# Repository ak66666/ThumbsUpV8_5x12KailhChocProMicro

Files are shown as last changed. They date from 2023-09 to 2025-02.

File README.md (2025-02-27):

# ThumbsUp! v8 5x12 Keyboard for Kailh Choc and Gateron Low Profile switches dirven by ProMicro and pin-compatibles

Multilevel 58 Key Ergonomic Contoured Mechanical Keyboard.

The board uses Kailh Choc and Gateron Low Profile Switches with hot-swap sockets.

ProMicro or pin-compatible MCUs are supported, including Raspberry RP2040 with [QMK, see this fork.](https://github.com/ak66666/qmk_firmware/tree/thumbsup_20240523/keyboards/thumbsup)

Supports Proglide Cirque touchpad (up to 40mm diameter).

Can be made wireless with nice!nano v2 and a battery, [ZMK firmware.](https://github.com/ak66666/zmk-config/tree/master)

# Photos

Black PCBs - v8 with Kailh Choc switches, PCBs are 1.6mm thick
Red PCBs - v8b with Gateron Low Profile switches, PCB thickness is 1.2mm, GLP switch pins are too short (or rather are tapered at the ends too much), what creates poor/unstable contact with the sockets in 1.6mm PCBs.

v8 with Kailh Choc Blue switches
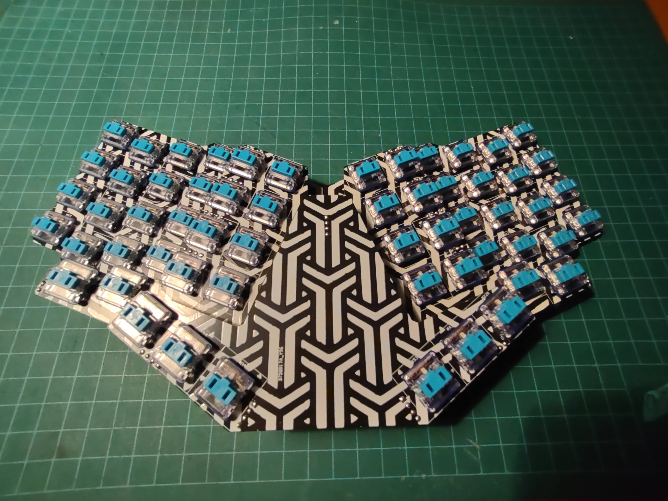
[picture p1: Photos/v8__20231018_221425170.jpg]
v8 with Kailh Choc Blue switches

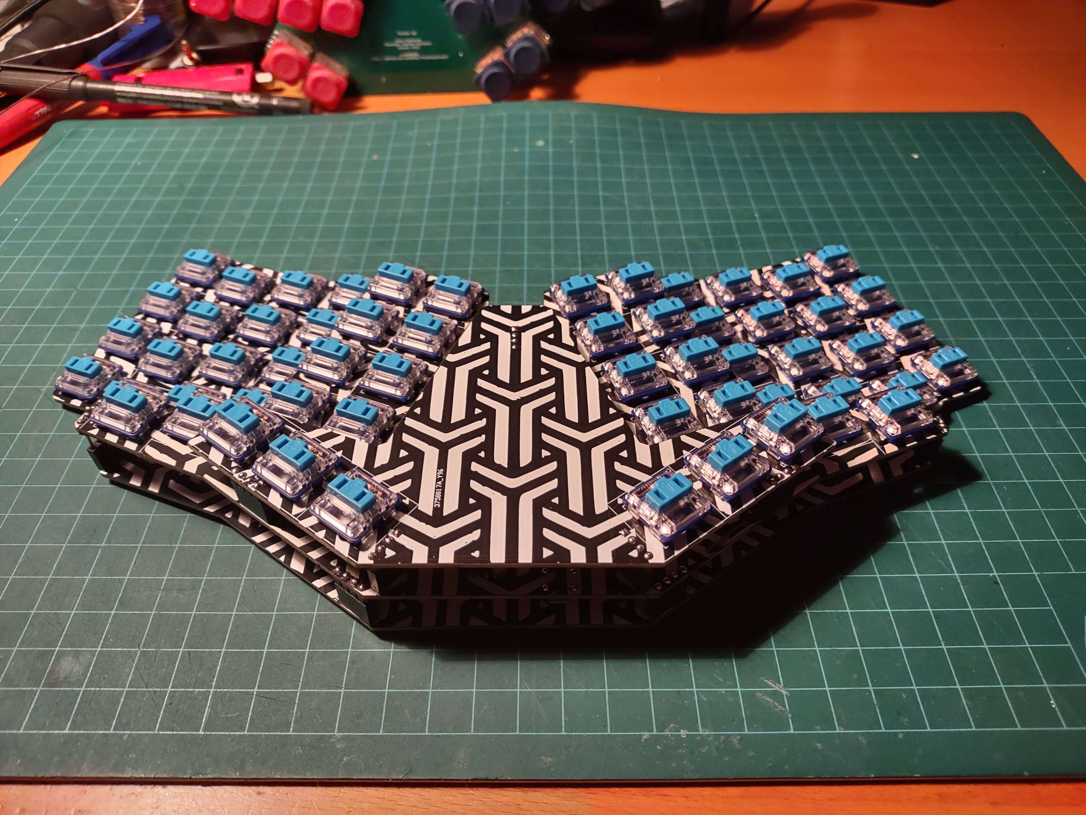
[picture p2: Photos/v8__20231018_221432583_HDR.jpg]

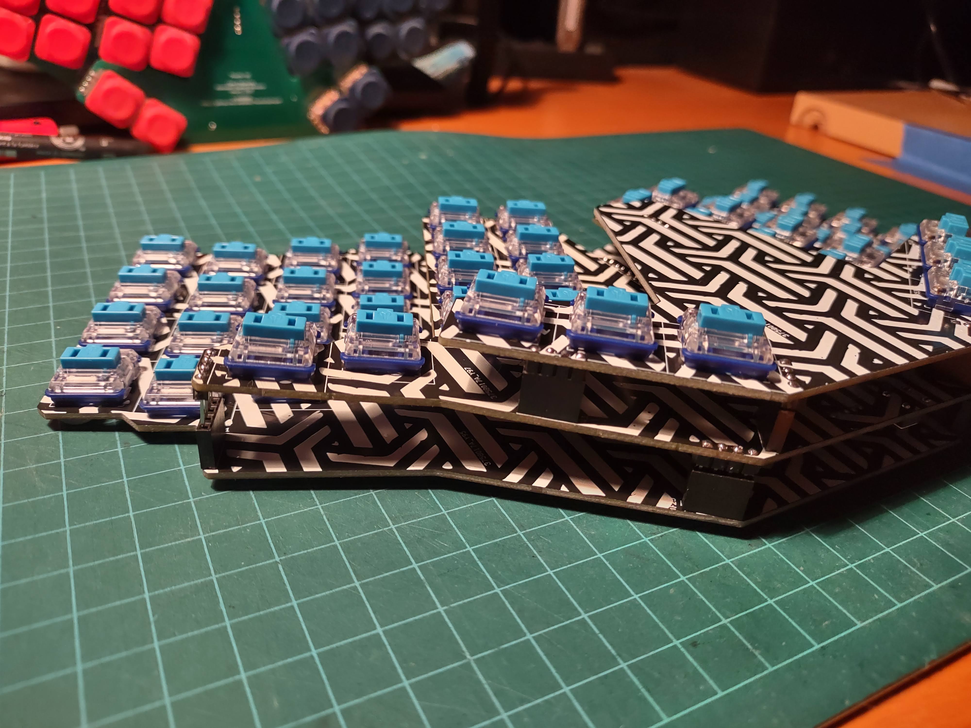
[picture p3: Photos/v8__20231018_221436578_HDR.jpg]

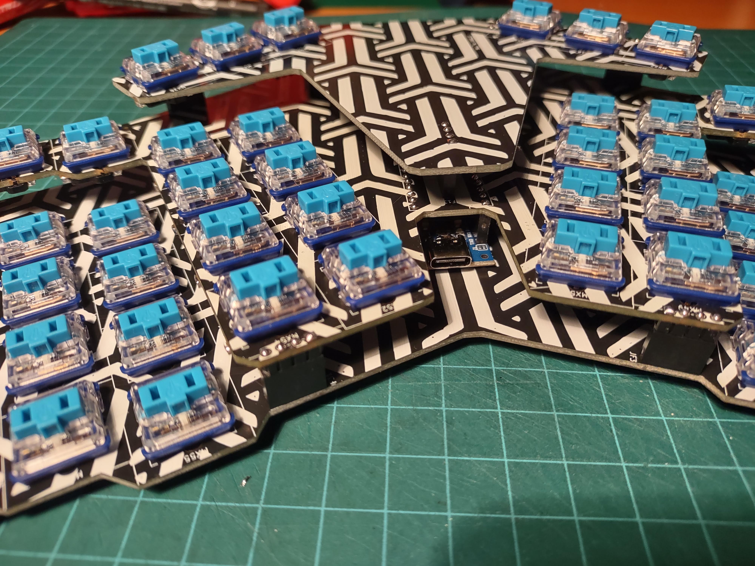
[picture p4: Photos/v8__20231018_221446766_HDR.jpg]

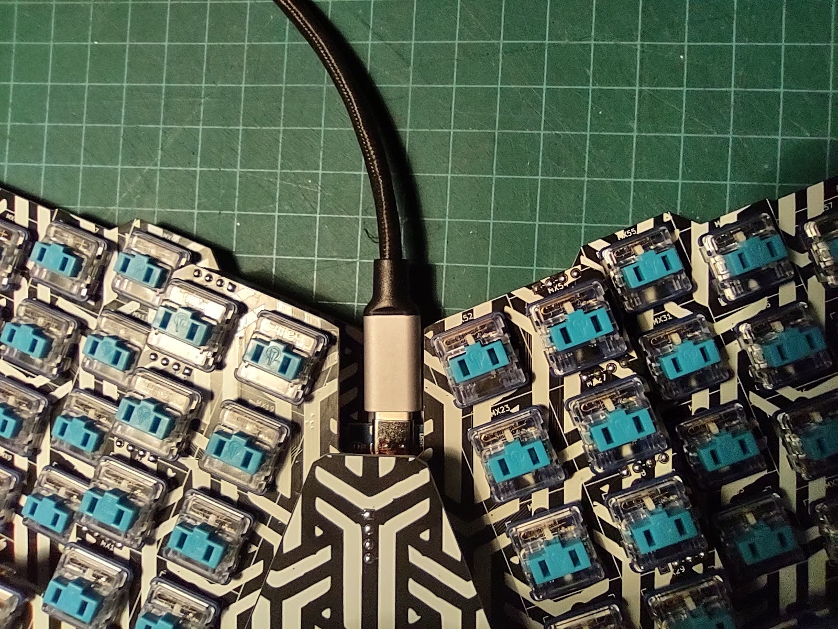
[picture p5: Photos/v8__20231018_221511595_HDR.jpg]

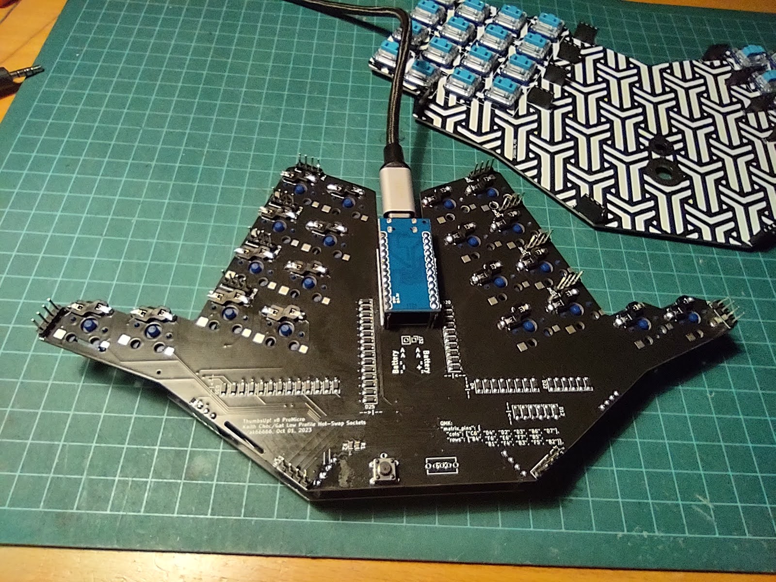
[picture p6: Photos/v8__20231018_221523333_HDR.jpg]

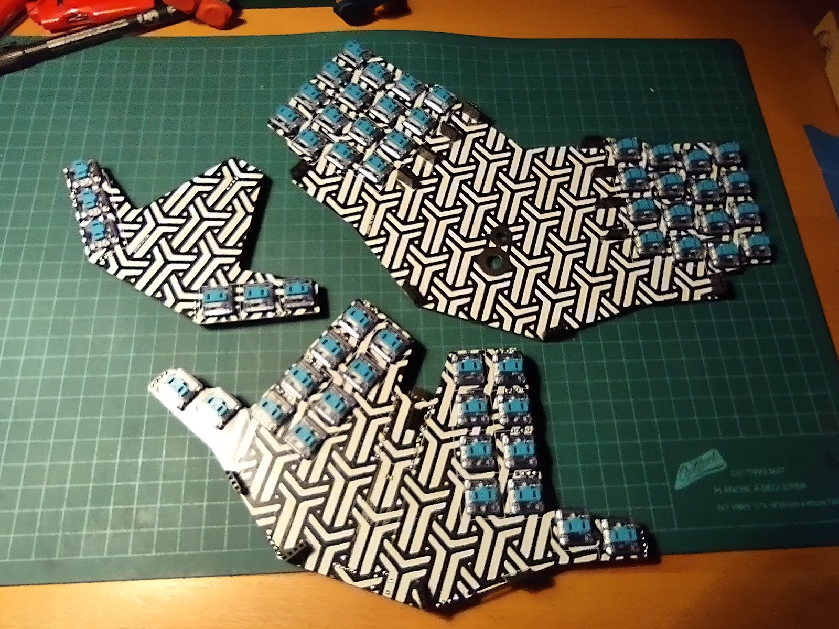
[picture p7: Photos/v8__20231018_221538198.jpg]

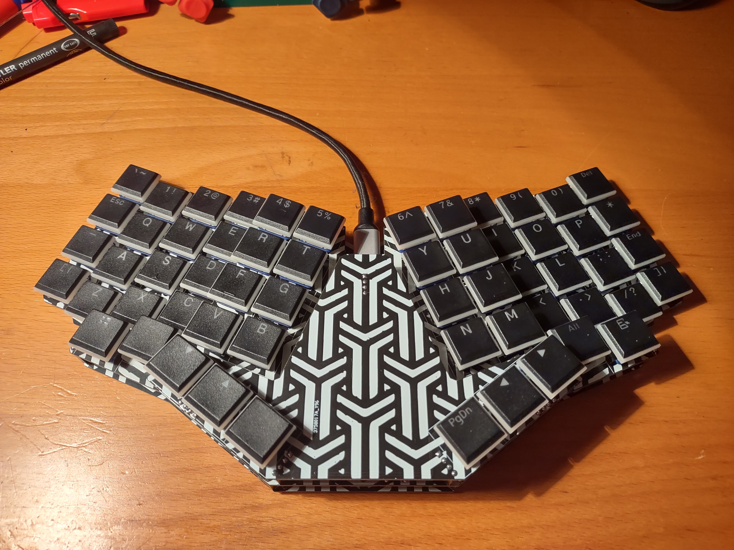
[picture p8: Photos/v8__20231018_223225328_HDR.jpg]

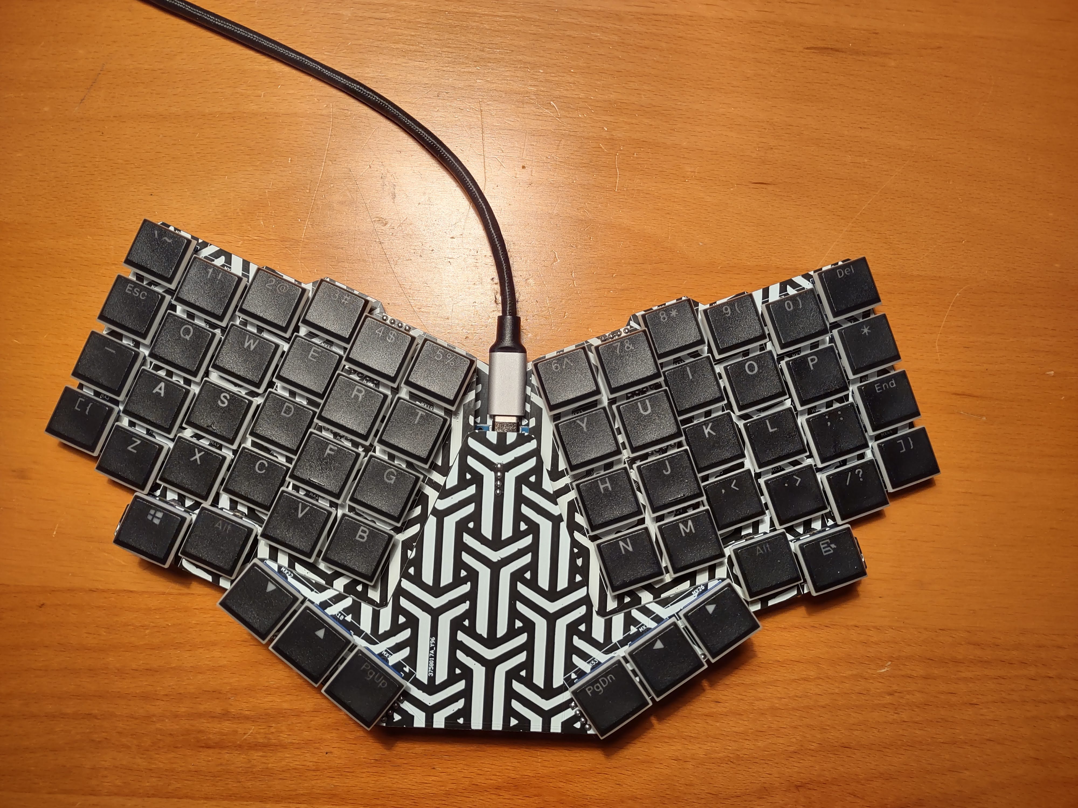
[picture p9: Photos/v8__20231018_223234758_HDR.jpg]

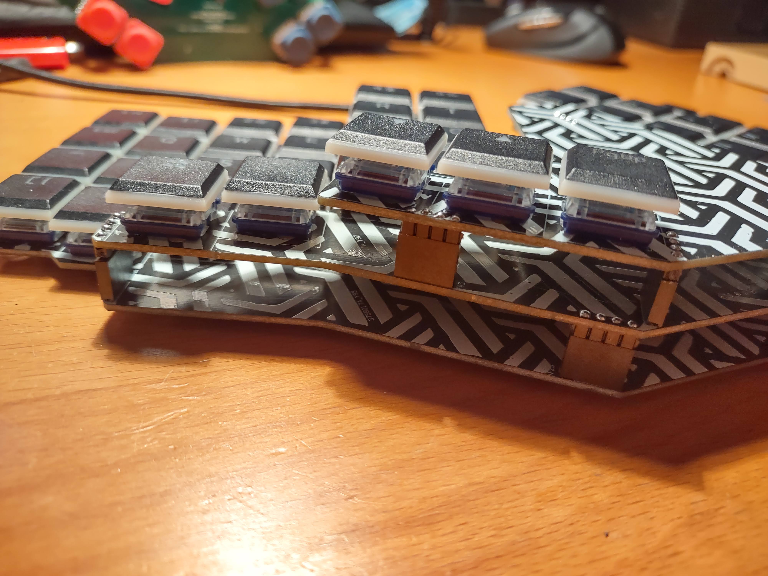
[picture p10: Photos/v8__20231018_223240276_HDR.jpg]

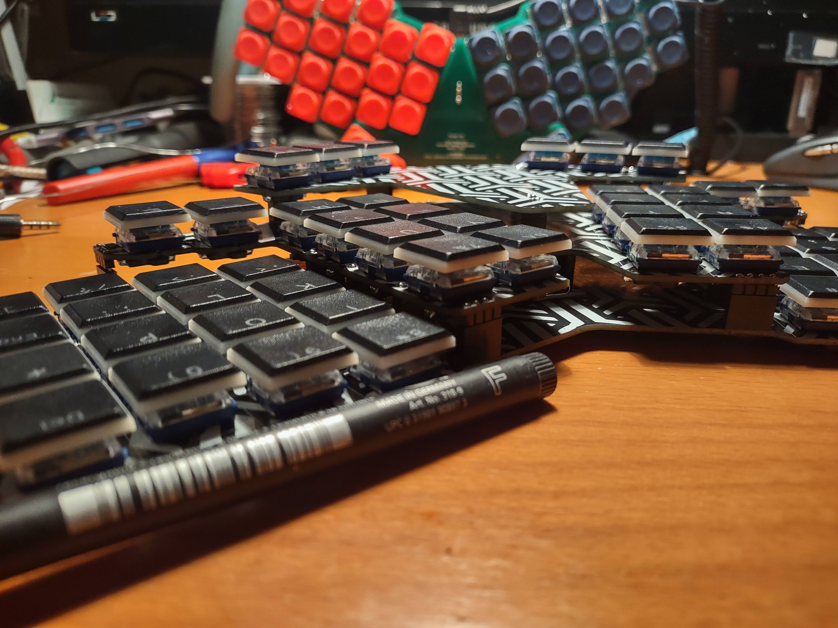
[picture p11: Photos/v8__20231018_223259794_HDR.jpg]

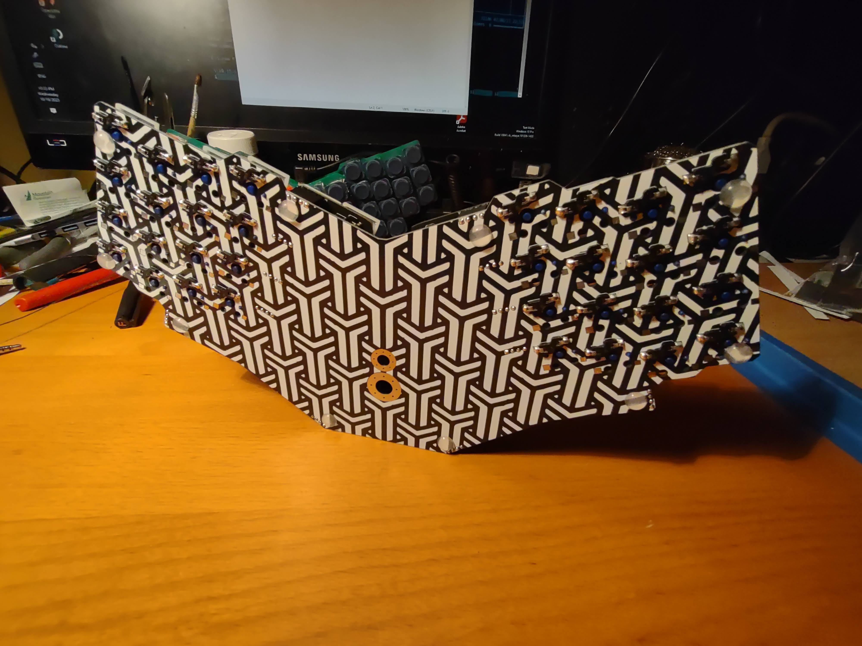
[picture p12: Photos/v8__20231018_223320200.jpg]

ThumbsUp! v2 and v8
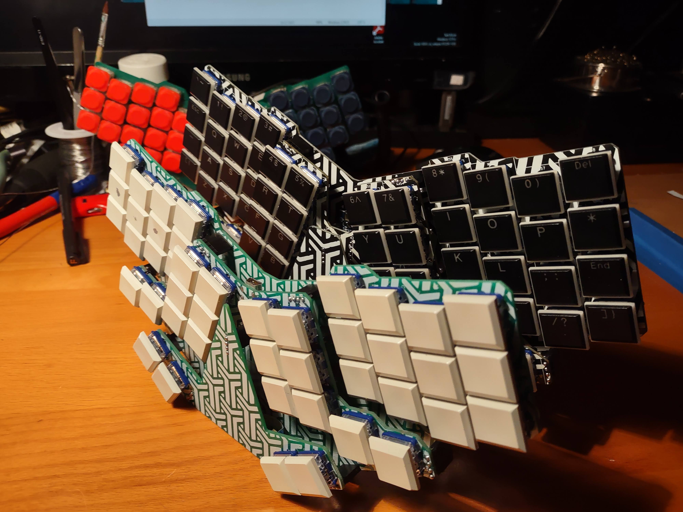
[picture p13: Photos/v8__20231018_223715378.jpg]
ThumbsUp! v2 and v8

ThumbsUp! v8 and v5
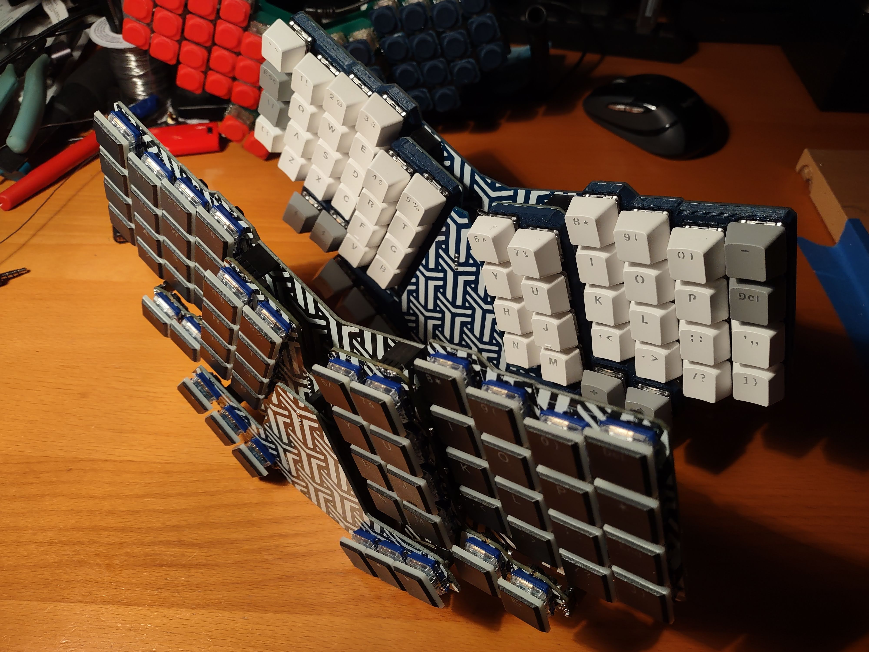
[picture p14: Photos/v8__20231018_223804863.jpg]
ThumbsUp! v8 and v5

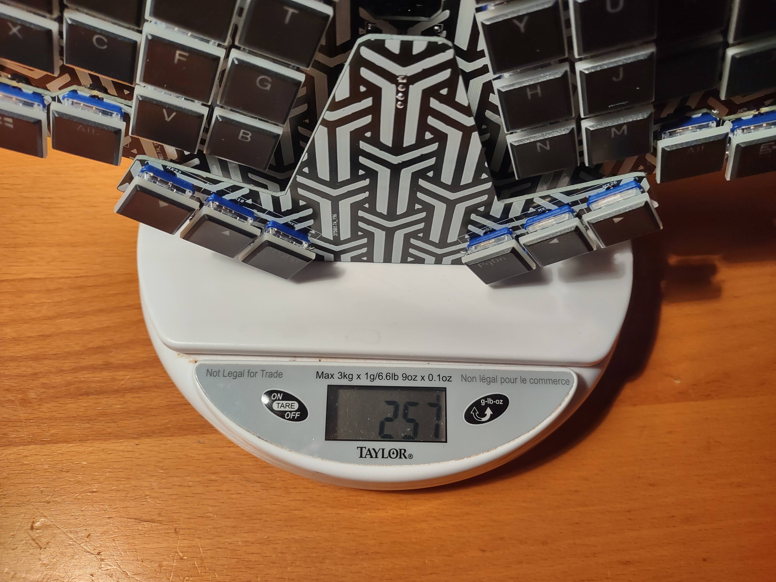
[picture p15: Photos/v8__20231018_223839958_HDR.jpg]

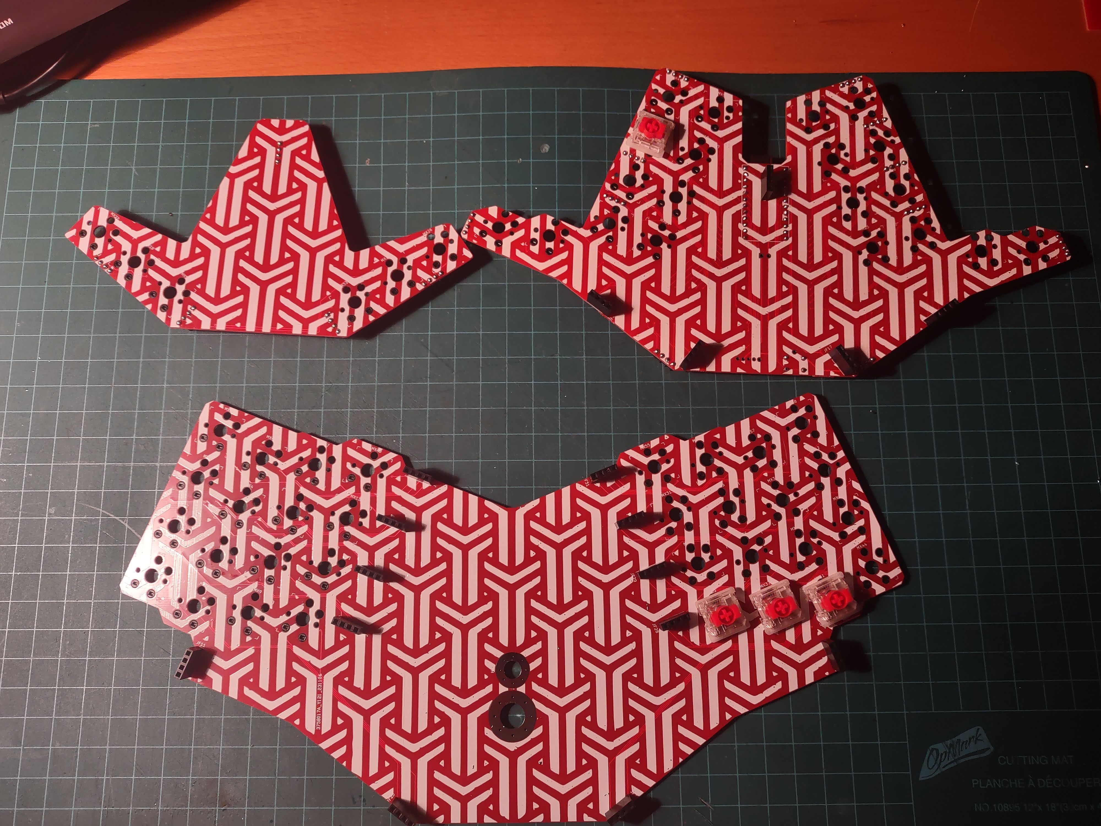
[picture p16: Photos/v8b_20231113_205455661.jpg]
ThumbsUp! v8b in progress

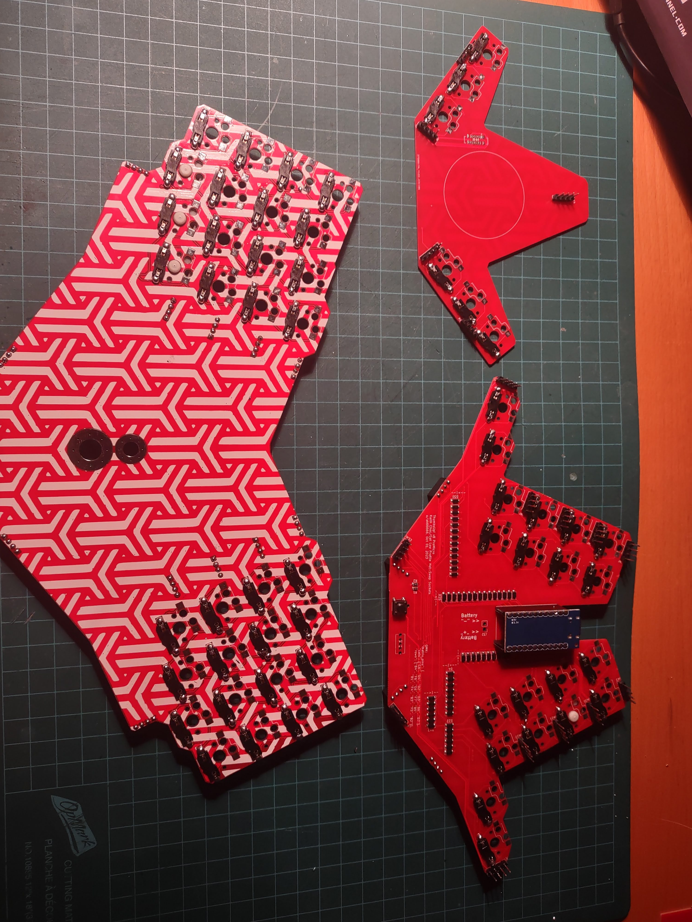
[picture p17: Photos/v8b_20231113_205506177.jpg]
ThumbsUp! v8b with GLP sockets - assembled

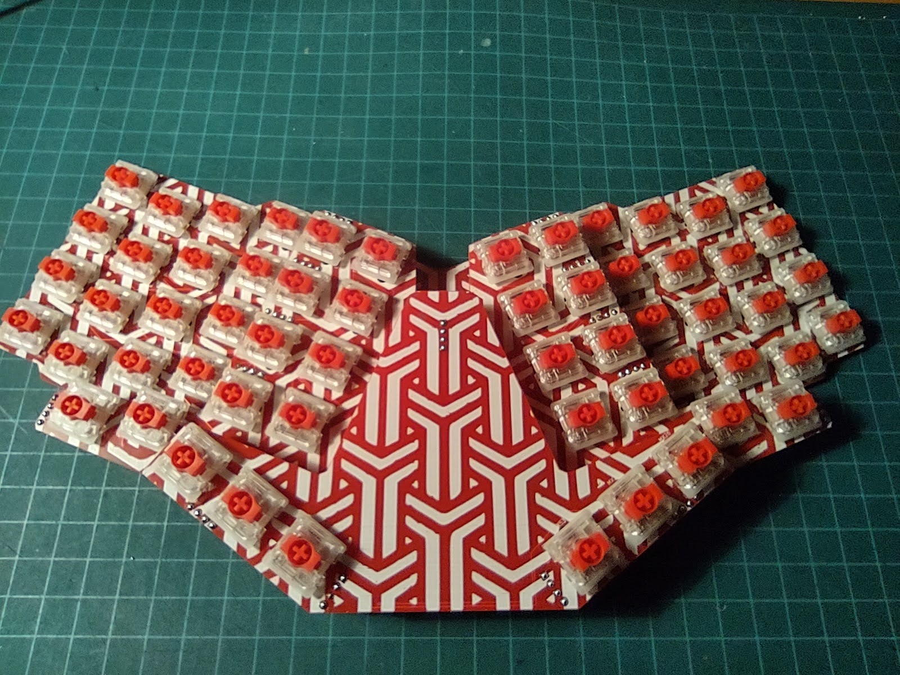
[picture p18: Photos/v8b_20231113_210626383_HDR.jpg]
ThumbsUp! v8b with Gateron Low Profile switches installed

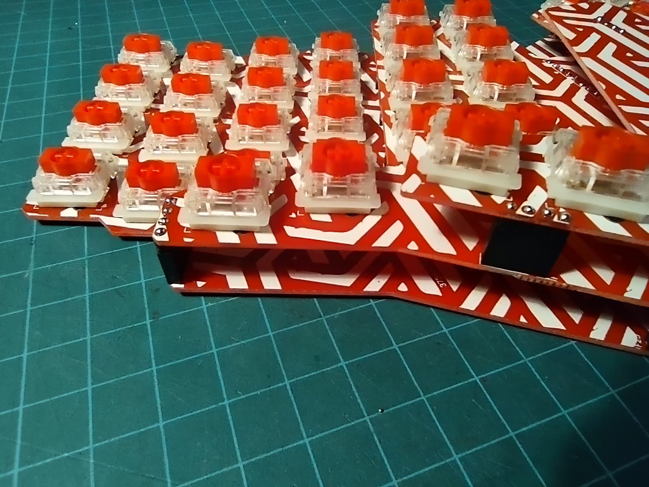
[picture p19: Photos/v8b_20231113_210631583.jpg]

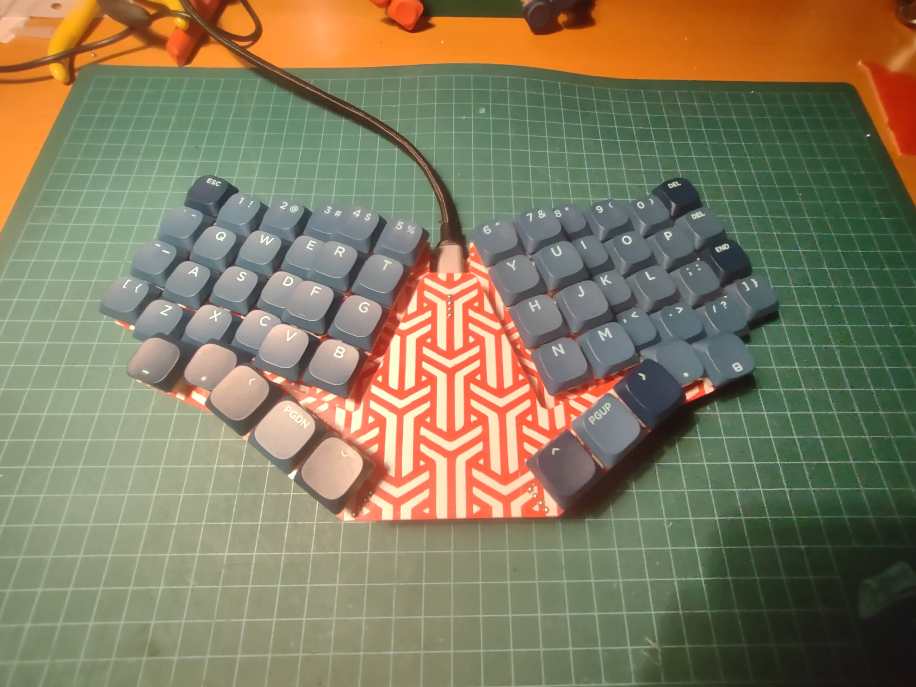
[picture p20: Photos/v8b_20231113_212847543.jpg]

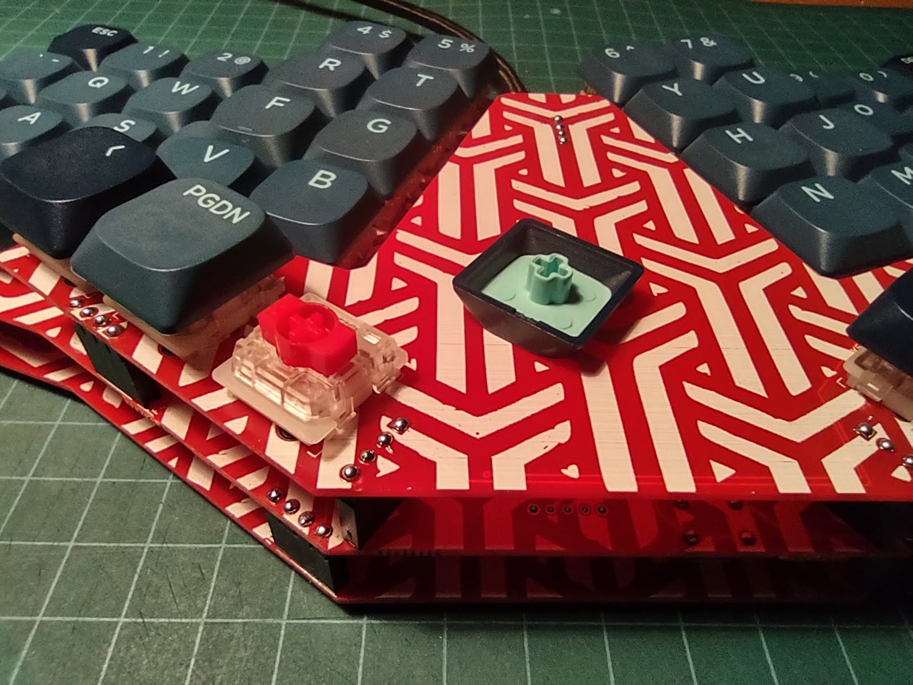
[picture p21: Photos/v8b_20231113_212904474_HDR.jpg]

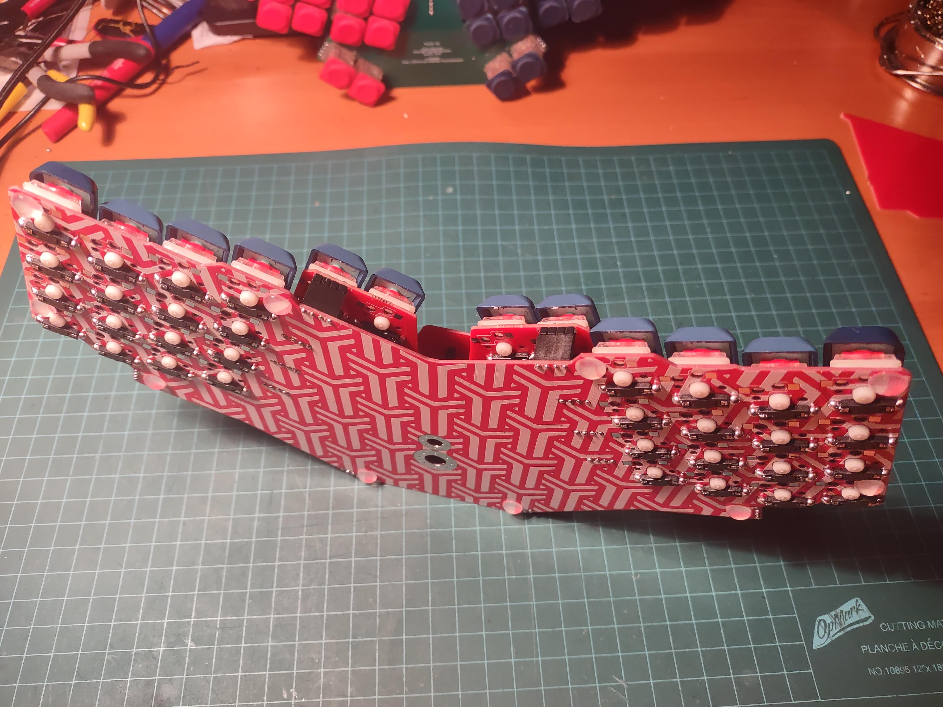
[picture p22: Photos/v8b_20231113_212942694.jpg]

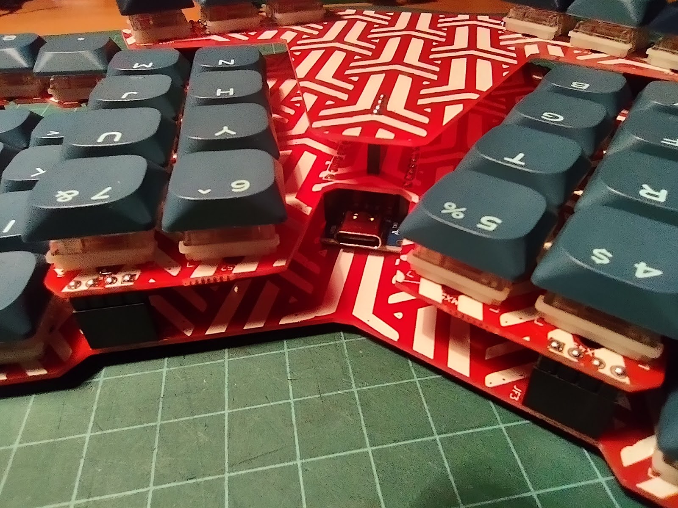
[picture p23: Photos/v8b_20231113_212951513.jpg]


# Firmware
The default firmware is here:
QMK Firmware

# Here you can buy it
ThubmsUp! v8 with Kailh Choc switches
ThumbsUp! v8b with Gateron Low Profile switches

# More info
Blogspot

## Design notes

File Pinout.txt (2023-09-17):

    "matrix_pins": {
        "cols": ["C6", "D4", "D2", "D3", "B6", "D7"],
        "rows": ["B4", "F6", "E6", "F7", "B5", "B1", "F4", "B3", "F5", "B2"]
    },

LEFT SIDE
D3	COL3
D2	COL2
GND
GND   
D1
D0
D4 	COL1
C6	COL0
D7	COL5
E6	ROWL1
B4	ROWL0
B5	ROWL2

RIGHT SIDE
RAW
GND
RESET
VCC
F4	ROWL3
F5	ROWL4
F6	ROWR0
F7	ROWR1
B1	ROWR2
B3	ROWR3
B2	ROWR4
B6	COL4

Columns: C6, D4, D2, D3, B6, D7
Rows: L0, R0, L1, R1, ...
B4, F6, E6, F7, B5, B1, F4, B3, F5, B2

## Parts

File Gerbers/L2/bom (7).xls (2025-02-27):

Comment | Designator | Footprint | JLCPCB Part #
D_Small | D58,D57,D56,D55,D54,D53,D52,D51,D50,D49,D48,D47,D46,D45,D44,D43,D42,D41,D40,D39,D38,D37,D36,D35,D34,D33,D32,D31,D30,D29,D28,D27,D26,D25,D24,D23,D22,D21,D20,D19,D18,D17,D16,D15,D14,D13,D12,D11,D10,D9,D8,D7,D6,D5,D4,D3,D2,D1 | D_SOD-123 | C81598
5.1K | R2,R1 | R_0805_2012Metric | C27834

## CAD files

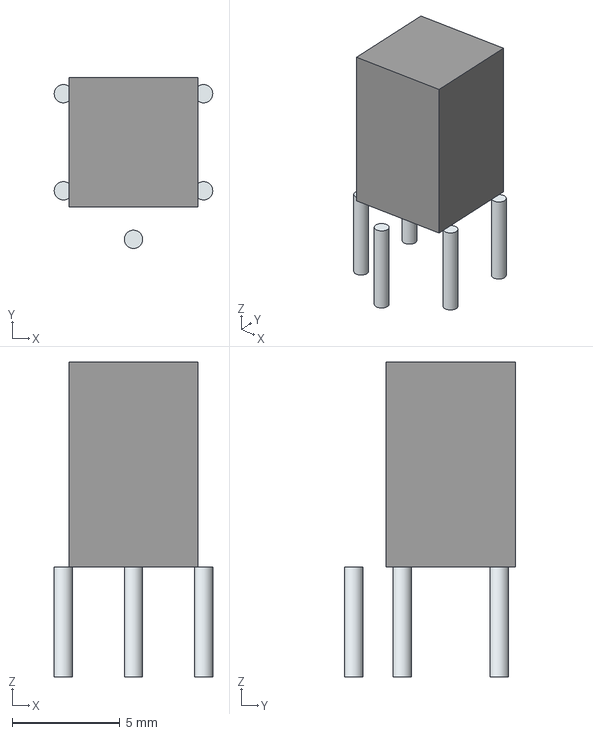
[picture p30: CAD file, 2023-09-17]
LIB_BUTT-4/BUTT-4/3D/BUTT-4.stp
7.35 x 7.92 x 14.6 mm
Leads x 5

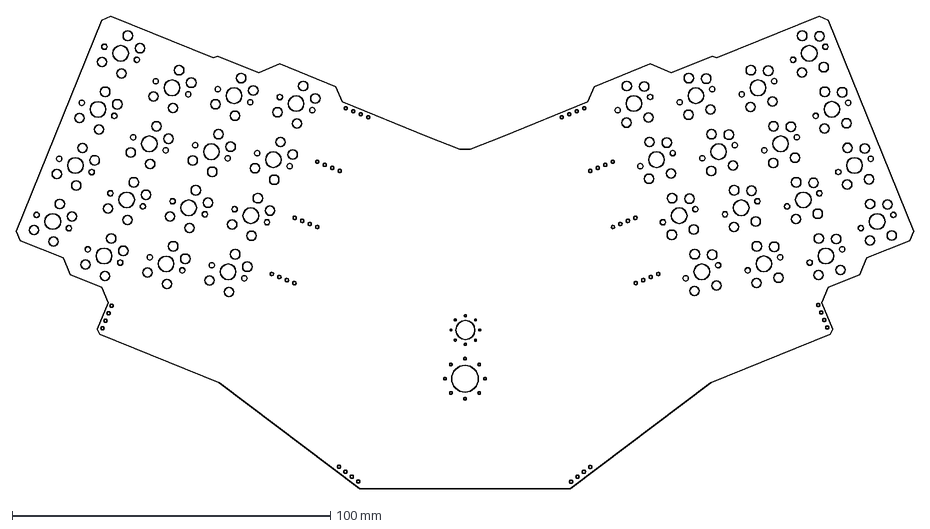
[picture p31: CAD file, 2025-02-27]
v8.dxf
282.0 x 148.4 mm

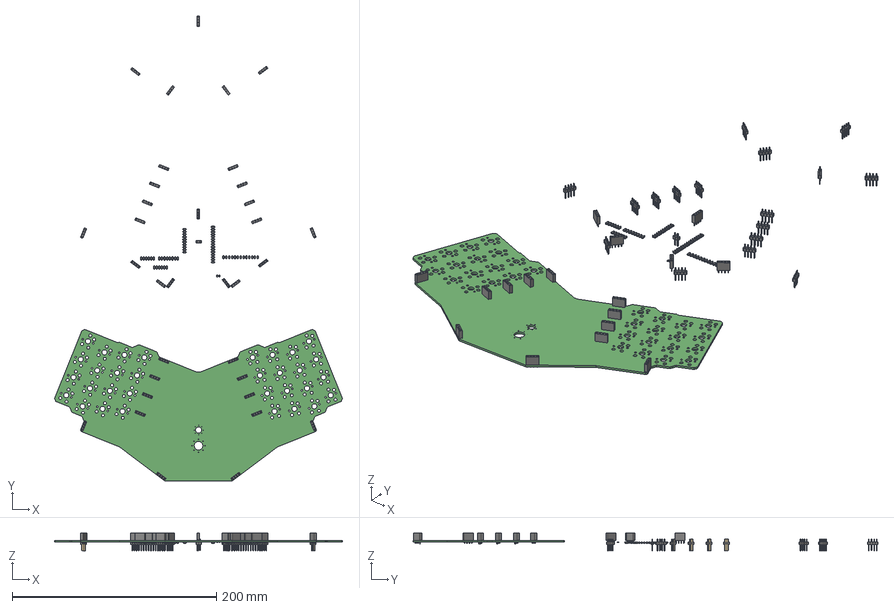
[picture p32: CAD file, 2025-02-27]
ThumbsUp.step
282.0 x 455.3 x 17.2 mm

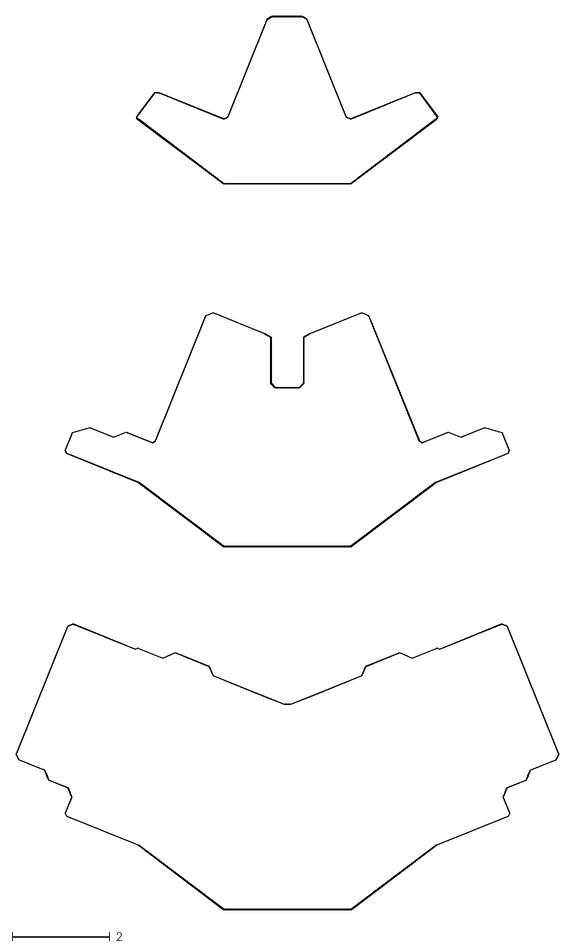
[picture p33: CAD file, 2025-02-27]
ThumbsUp-Edge_Cuts.dxf
11.1 x 18.3

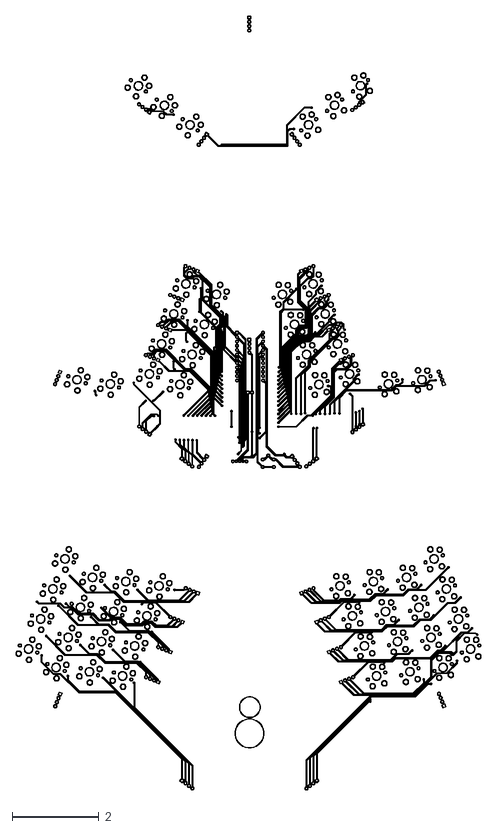
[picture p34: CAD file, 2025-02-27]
ThumbsUp-F_Cu.dxf
10.7 x 17.9

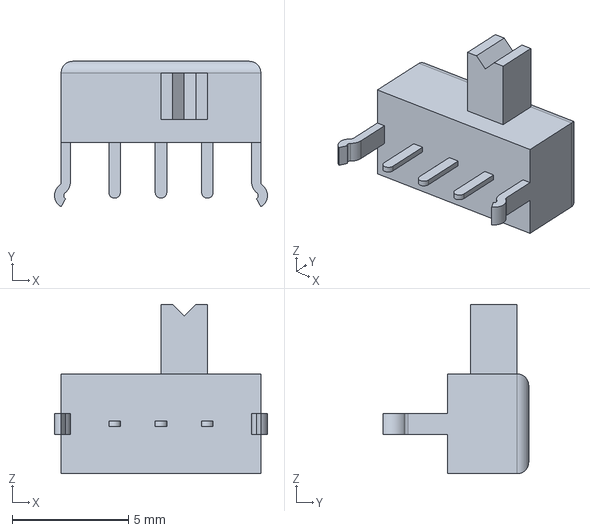
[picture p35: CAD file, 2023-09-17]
1825232-1/3D/1825232-1.stp
9.17 x 6.27 x 7.30 mm

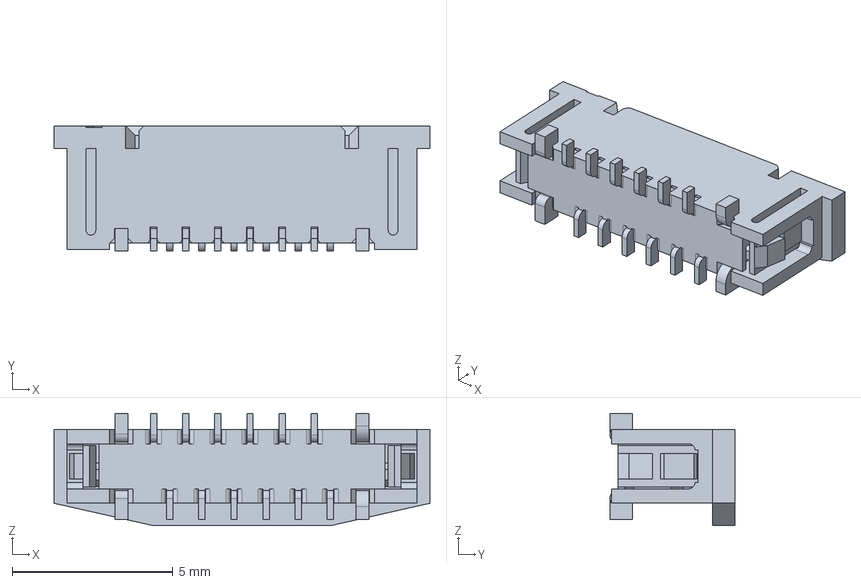
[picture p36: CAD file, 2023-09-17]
Molex 52559-1233/52559-1233/3D/52559-1233.stp
11.7 x 3.90 x 3.50 mm

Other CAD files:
1825232-1/Allegro/18252321.psm
1825232-1/DEHDL/1825232_1/chips/chips.prt
LIB_BUTT-4/BUTT-4/Allegro/butt4.psm
LIB_BUTT-4/BUTT-4/DEHDL/butt_4/chips/chips.prt
Molex 52559-1233/52559-1233/Allegro/525591233.psm
Molex 52559-1233/52559-1233/DEHDL/52559_1233/chips/chips.prt
ThumbsUp-B_Mask.dxf
ThumbsUp-B_Paste.dxf
ThumbsUp-F_Mask.dxf
ThumbsUp-F_Paste.dxf

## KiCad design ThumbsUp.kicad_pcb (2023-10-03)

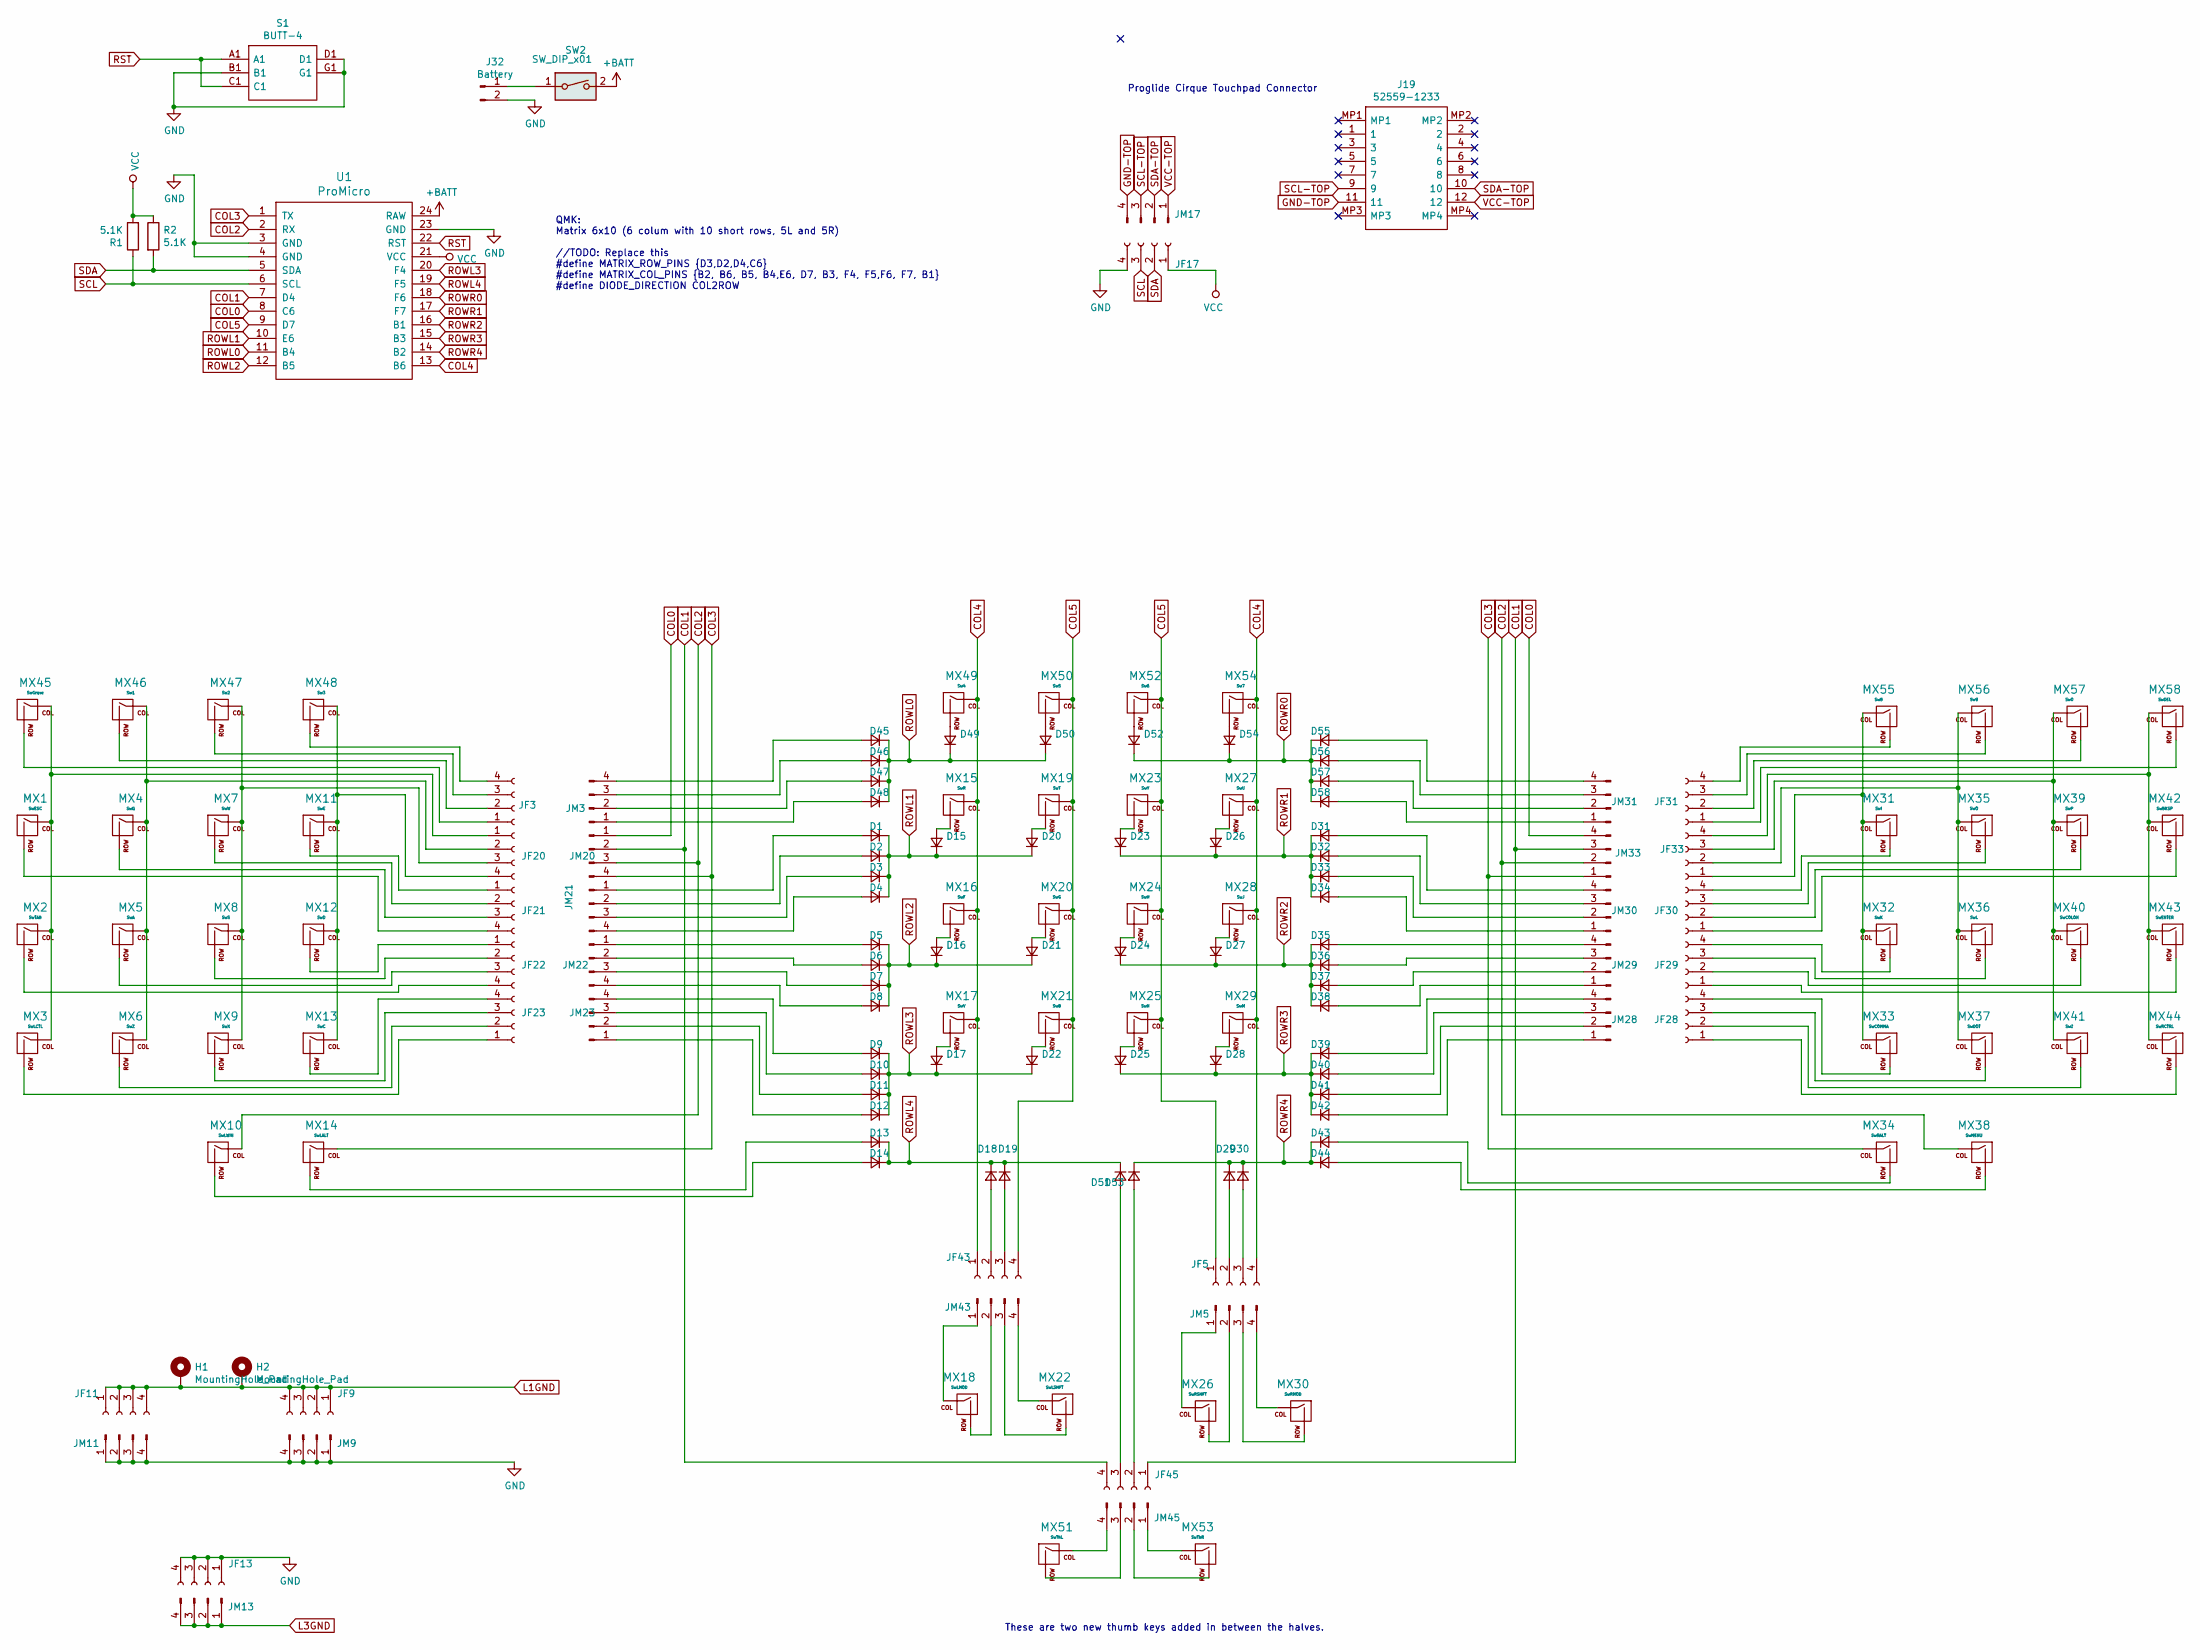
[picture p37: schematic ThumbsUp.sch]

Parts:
D1, D2, D3, D4, D5, D6, D7, D8, D9, D10, D11, D12, D13, D14, D15, D16, D17, D18, D19, D20, D21, D22, D23, D24, D25, D26, D27, D28, D29, D30, D31, D32, D33, D34, D35, D36, D37, D38, D39, D40, D41, D42, D43, D44, D45, D46, D47, D48, D49, D50, D51, D52, D53, D54, D55, D56, D57, D58: D_Small; D_SOD-123
H1: MountingHole_Pad; MountingHole_6mm_Pad_Via
H2: MountingHole_Pad; MountingHole_8.4mm_M8_Pad_Via
J19: 52559-1233; 525591233; Mouser Part Number 538-52559-1233
J32: Battery; PinHeader_1x02_P2.54mm_Vertical
JF3, JF5, JF20, JF21, JF22, JF23, JF28, JF29, JF30, JF31, JF33, JF43, JF45: Conn_01x04_Female; PinSocket_1x04_P2.54mm_Vertical
JF9, JF11, JF13, JF17: Raiser_Female; PinSocket_1x04_P2.54mm_Vertical
JM3, JM20, JM21, JM22, JM23, JM28, JM29, JM30, JM31, JM33, JM43, JM45: Conn_01x04_Male; PinHeader_1x04_P2.54mm_Vertical
JM5: Male; PinHeader_1x04_P2.54mm_Vertical
JM9, JM11, JM13, JM17: Raiser_Male; PinHeader_1x04_P2.54mm_Vertical
MX1: SwESC; PG1350_GLv2
MX2: SwTAB; PG1350_GLv2
MX3: SwLCTL; PG1350_GLv2
MX4: SwQ; PG1350_GLv2
MX5: SwA; PG1350_GLv2
MX6: SwZ; PG1350_GLv2
MX7: SwW; PG1350_GLv2
MX8: SwS; PG1350_GLv2
MX9: SwX; PG1350_GLv2
MX10: SwLWIN; PG1350_GLv2
MX11: SwE; PG1350_GLv2
MX12: SwD; PG1350_GLv2
MX13: SwC; PG1350_GLv2
MX14: SwLALT; PG1350_GLv2
MX15: SwR; PG1350_GLv2
MX16: SwF; PG1350_GLv2
MX17: SwV; PG1350_GLv2
MX18: SwLMOD; PG1350_GLv2
MX19: SwT; PG1350_GLv2
MX20: SwG; PG1350_GLv2
MX21: SwB; PG1350_GLv2
MX22: SwLSHFT; PG1350_GLv2
MX23: SwY; PG1350_GLv2
MX24: SwH; PG1350_GLv2
MX25: SwN; PG1350_GLv2
MX26: SwRSHFT; PG1350_GLv2
MX27: SwU; PG1350_GLv2
MX28: SwJ; PG1350_GLv2
MX29: SwM; PG1350_GLv2
MX30: SwRMOD; PG1350_GLv2
MX31: SwI; PG1350_GLv2
MX32: SwK; PG1350_GLv2
MX33: SwCOMMA; PG1350_GLv2
MX34: SwRALT; PG1350_GLv2
MX35: SwO; PG1350_GLv2
MX36: SwL; PG1350_GLv2
MX37: SwDOT; PG1350_GLv2
MX38: SwMENU; PG1350_GLv2
MX39: SwP; PG1350_GLv2
MX40: SwCOLON; PG1350_GLv2
MX41: Sw?; PG1350_GLv2
MX42: SwBKSP; PG1350_GLv2
MX43: SwENTER; PG1350_GLv2
MX44: SwRCTRL; PG1350_GLv2
MX45: SwGrave; PG1350_GLv2
MX46: Sw1; PG1350_GLv2
MX47: Sw2; PG1350_GLv2
MX48: Sw3; PG1350_GLv2
MX49: Sw4; PG1350_GLv2
MX50: Sw5; PG1350_GLv2
MX51: SwThL; PG1350_GLv2
MX52: Sw6; PG1350_GLv2
MX53: SwThR; PG1350_GLv2
MX54: Sw7; PG1350_GLv2
MX55: Sw8; PG1350_GLv2
MX56: Sw9; PG1350_GLv2
MX57: Sw0; PG1350_GLv2
MX58: SwDEL; PG1350_GLv2
R1, R2: 5.1K; R_0805_2012Metric
S1: BUTT-4; BUTT4; Manufacturer_Part_Number BUTT-4; Mouser Part Number 992-BUTT-4
SW2: SW_DIP_x01; 18252321
U1: ProMicro

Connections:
+BATT: SW2.2, U1.24 (RAW)
COL0: JM20.1, JM33.4, U1.8 (C6)
COL1: JF45.1, JF45.4, JM20.2, JM33.3, U1.7 (D4)
COL2: JM20.3, JM33.2, MX10.1 (COL), MX38.1 (COL), U1.2 (RX)
COL3: JM20.4, JM33.1, MX14.1 (COL), MX34.1 (COL), U1.1 (TX)
COL4: JF5.4, JF43.1, MX15.1 (COL), MX16.1 (COL), MX17.1 (COL), MX27.1 (COL), MX28.1 (COL), MX29.1 (COL), MX49.1 (COL), MX54.1 (COL), U1.13 (B6)
COL5: JF5.1, JF43.4, MX19.1 (COL), MX20.1 (COL), MX21.1 (COL), MX23.1 (COL), MX24.1 (COL), MX25.1 (COL), MX50.1 (COL), MX52.1 (COL), U1.9 (D7)
GND: J32.2, JF13.1, JF13.2, JF13.3, JF13.4, JF17.4, JM9.1, JM9.2, JM9.3, JM9.4, JM11.1, JM11.2, JM11.3, JM11.4, S1.B1, S1.D1, S1.G1, U1.3 (GND), U1.4 (GND), U1.23 (GND)
GND-TOP: J19.11, JM17.4
L1GND: H1.1, H2.1, JF9.1, JF9.2, JF9.3, JF9.4, JF11.1, JF11.2, JF11.3, JF11.4
L3GND: JM13.1, JM13.2, JM13.3, JM13.4
unnamed: D1.2 (A), JM21.1
unnamed: D2.2 (A), JM21.2
unnamed: D3.2 (A), JM21.3
unnamed: D4.2 (A), JM21.4
unnamed: D5.2 (A), JM22.1
unnamed: D6.2 (A), JM22.2
unnamed: D7.2 (A), JM22.3
unnamed: D8.2 (A), JM22.4
unnamed: D9.2 (A), JM23.4
unnamed: D10.2 (A), JM23.3
unnamed: D11.2 (A), JM23.2
unnamed: D12.2 (A), JM23.1
unnamed: D13.2 (A), MX14.2 (ROW)
unnamed: D14.2 (A), MX10.2 (ROW)
unnamed: D15.2 (A), MX15.2 (ROW)
unnamed: D16.2 (A), MX16.2 (ROW)
unnamed: D17.2 (A), MX17.2 (ROW)
unnamed: D18.2 (A), JF43.2
unnamed: D19.2 (A), JF43.3
unnamed: D20.2 (A), MX19.2 (ROW)
unnamed: D21.2 (A), MX20.2 (ROW)
unnamed: D22.2 (A), MX21.2 (ROW)
unnamed: D23.2 (A), MX23.2 (ROW)
unnamed: D24.2 (A), MX24.2 (ROW)
unnamed: D25.2 (A), MX25.2 (ROW)
unnamed: D26.2 (A), MX27.2 (ROW)
unnamed: D27.2 (A), MX28.2 (ROW)
unnamed: D28.2 (A), MX29.2 (ROW)
unnamed: D29.2 (A), JF5.2
unnamed: D30.2 (A), JF5.3
unnamed: D31.2 (A), JM30.4
unnamed: D32.2 (A), JM30.3
unnamed: D33.2 (A), JM30.2
unnamed: D34.2 (A), JM30.1
unnamed: D35.2 (A), JM29.4
unnamed: D36.2 (A), JM29.3
unnamed: D37.2 (A), JM29.2
unnamed: D38.2 (A), JM29.1
unnamed: D39.2 (A), JM28.4
unnamed: D40.2 (A), JM28.3
unnamed: D41.2 (A), JM28.2
unnamed: D42.2 (A), JM28.1
unnamed: D43.2 (A), MX34.2 (ROW)
unnamed: D44.2 (A), MX38.2 (ROW)
unnamed: D45.2 (A), JM3.4
unnamed: D46.2 (A), JM3.3
unnamed: D47.2 (A), JM3.2
unnamed: D48.2 (A), JM3.1
unnamed: D49.2 (A), MX49.2 (ROW)
unnamed: D50.2 (A), MX50.2 (ROW)
unnamed: D51.2 (A), JF45.3
unnamed: D52.2 (A), MX52.2 (ROW)
unnamed: D53.2 (A), JF45.2
unnamed: D54.2 (A), MX54.2 (ROW)
unnamed: D55.2 (A), JM31.4
unnamed: D56.2 (A), JM31.3
unnamed: D57.2 (A), JM31.2
unnamed: D58.2 (A), JM31.1
unnamed: J32.1, SW2.1
unnamed: JF3.1, MX45.2 (ROW)
unnamed: JF3.2, MX46.2 (ROW)
unnamed: JF3.3, MX47.2 (ROW)
unnamed: JF3.4, MX48.2 (ROW)
unnamed: JF20.1, MX1.1 (COL), MX2.1 (COL), MX3.1 (COL), MX45.1 (COL)
unnamed: JF20.2, MX4.1 (COL), MX5.1 (COL), MX6.1 (COL), MX46.1 (COL)
unnamed: JF20.3, MX7.1 (COL), MX8.1 (COL), MX9.1 (COL), MX47.1 (COL)
unnamed: JF20.4, MX11.1 (COL), MX12.1 (COL), MX13.1 (COL), MX48.1 (COL)
unnamed: JF21.1, MX11.2 (ROW)
unnamed: JF21.2, MX7.2 (ROW)
unnamed: JF21.3, MX4.2 (ROW)
unnamed: JF21.4, MX1.2 (ROW)
unnamed: JF22.1, MX12.2 (ROW)
unnamed: JF22.2, MX8.2 (ROW)
unnamed: JF22.3, MX5.2 (ROW)
unnamed: JF22.4, MX2.2 (ROW)
unnamed: JF23.1, MX3.2 (ROW)
unnamed: JF23.2, MX6.2 (ROW)
unnamed: JF23.3, MX9.2 (ROW)
unnamed: JF23.4, MX13.2 (ROW)
unnamed: JF28.1, MX44.2 (ROW)
unnamed: JF28.2, MX41.2 (ROW)
unnamed: JF28.3, MX37.2 (ROW)
unnamed: JF28.4, MX33.2 (ROW)
unnamed: JF29.1, MX43.2 (ROW)
unnamed: JF29.2, MX40.2 (ROW)
unnamed: JF29.3, MX36.2 (ROW)
unnamed: JF29.4, MX32.2 (ROW)
unnamed: JF30.1, MX42.2 (ROW)
unnamed: JF30.2, MX39.2 (ROW)
unnamed: JF30.3, MX35.2 (ROW)
unnamed: JF30.4, MX31.2 (ROW)
unnamed: JF31.1, MX58.2 (ROW)
unnamed: JF31.2, MX57.2 (ROW)
unnamed: JF31.3, MX56.2 (ROW)
unnamed: JF31.4, MX55.2 (ROW)
unnamed: JF33.1, MX31.1 (COL), MX32.1 (COL), MX33.1 (COL), MX55.1 (COL)
unnamed: JF33.2, MX35.1 (COL), MX36.1 (COL), MX37.1 (COL), MX56.1 (COL)
unnamed: JF33.3, MX39.1 (COL), MX40.1 (COL), MX41.1 (COL), MX57.1 (COL)
unnamed: JF33.4, MX42.1 (COL), MX43.1 (COL), MX44.1 (COL), MX58.1 (COL)
unnamed: JM5.1, MX26.1 (COL)
unnamed: JM5.2, MX26.2 (ROW)
unnamed: JM5.3, MX30.2 (ROW)
unnamed: JM5.4, MX30.1 (COL)
unnamed: JM43.1, MX18.1 (COL)
unnamed: JM43.2, MX18.2 (ROW)
unnamed: JM43.3, MX22.2 (ROW)
unnamed: JM43.4, MX22.1 (COL)
unnamed: JM45.1, MX53.1 (COL)
unnamed: JM45.2, MX53.2 (ROW)
unnamed: JM45.3, MX51.2 (ROW)
unnamed: JM45.4, MX51.1 (COL)
ROWL0: D45.1 (K), D46.1 (K), D47.1 (K), D48.1 (K), D49.1 (K), D50.1 (K), U1.11 (B4)
ROWL1: D1.1 (K), D2.1 (K), D3.1 (K), D4.1 (K), D15.1 (K), D20.1 (K), U1.10 (E6)
ROWL2: D5.1 (K), D6.1 (K), D7.1 (K), D8.1 (K), D16.1 (K), D21.1 (K), U1.12 (B5)
ROWL3: D9.1 (K), D10.1 (K), D11.1 (K), D12.1 (K), D17.1 (K), D22.1 (K), U1.20 (F4)
ROWL4: D13.1 (K), D14.1 (K), D18.1 (K), D19.1 (K), D51.1 (K), U1.19 (F5)
ROWR0: D52.1 (K), D54.1 (K), D55.1 (K), D56.1 (K), D57.1 (K), D58.1 (K), U1.18 (F6)
ROWR1: D23.1 (K), D26.1 (K), D31.1 (K), D32.1 (K), D33.1 (K), D34.1 (K), U1.17 (F7)
ROWR2: D24.1 (K), D27.1 (K), D35.1 (K), D36.1 (K), D37.1 (K), D38.1 (K), U1.16 (B1)
ROWR3: D25.1 (K), D28.1 (K), D39.1 (K), D40.1 (K), D41.1 (K), D42.1 (K), U1.15 (B3)
ROWR4: D29.1 (K), D30.1 (K), D43.1 (K), D44.1 (K), D53.1 (K), U1.14 (B2)
RST: S1.A1, S1.C1, U1.22 (RST)
SCL: JF17.3, R1.1, U1.6 (SCL)
SCL-TOP: J19.9, JM17.3
SDA: JF17.2, R2.2, U1.5 (SDA)
SDA-TOP: J19.10, JM17.2
VCC: JF17.1, R1.2, R2.1, U1.21 (VCC)
VCC-TOP: J19.12, JM17.1

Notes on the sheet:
QMK: Matrix 6x10 (6 colum with 10 short rows, 5L and 5R) //TODO: Replace this #define MATRIX_ROW_PINS {D3,D2,D4,C6} #define MATRIX_COL_PINS {B2, B6, B5, B4,E6, D7, B3, F4, F5,F6, F7, B1} #define DIODE_DIRECTION COL2ROW
Proglide Cirque Touchpad Connector
These are two new thumb keys added in between the halves.

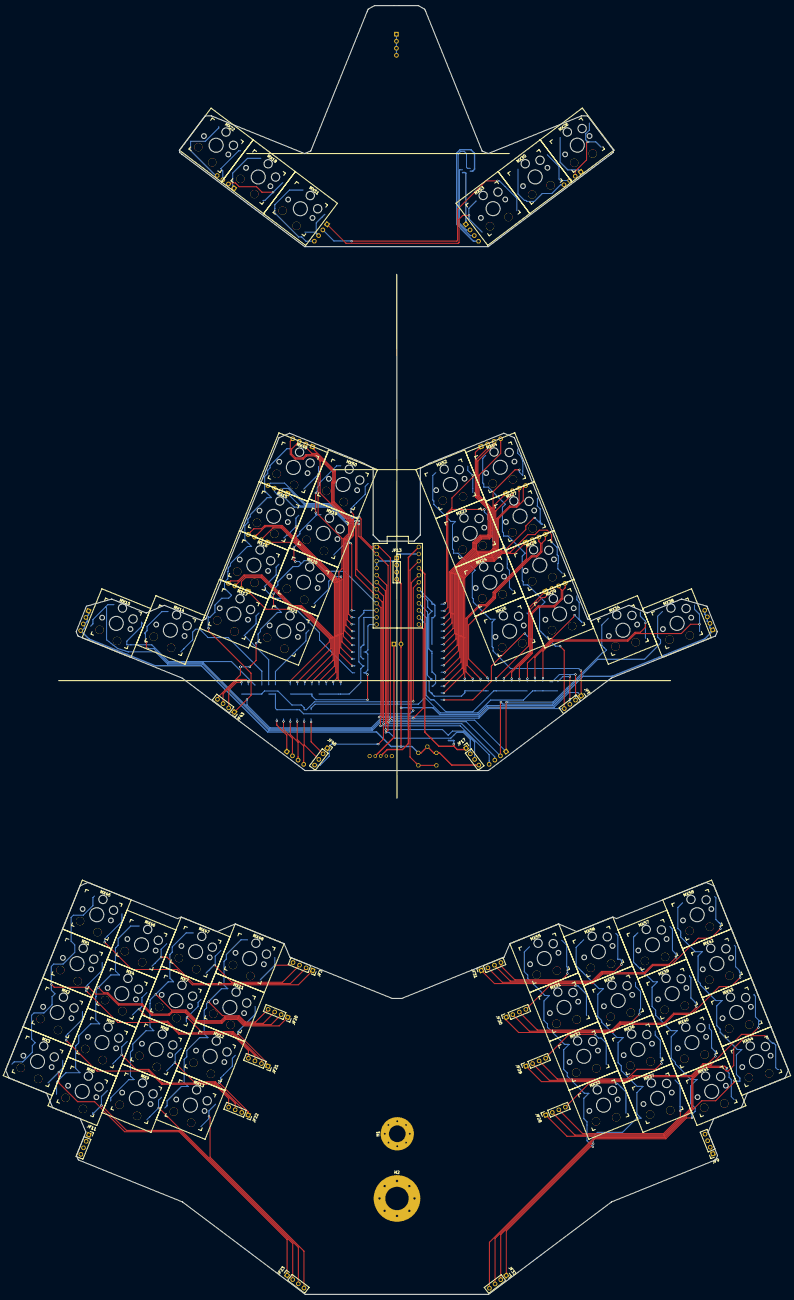
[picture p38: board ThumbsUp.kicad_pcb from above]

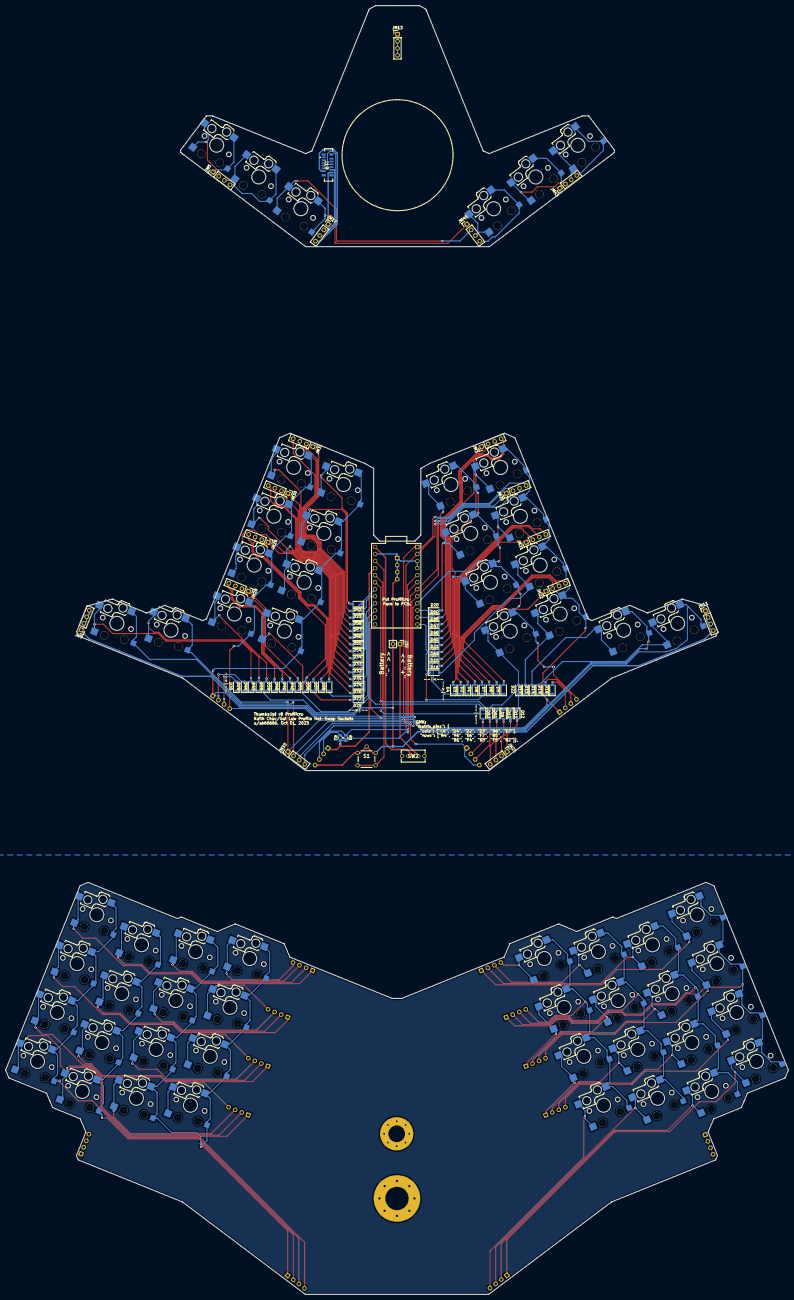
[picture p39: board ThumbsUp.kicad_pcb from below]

Board: 2 copper layers, 282.0 x 464.4 mm, 159 parts (81 on the bottom side), 139 nets.

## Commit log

2023-09-17 Initiated the v8
    [1825232-1.SchLib, 1825232-1.stp, 18252321.PcbLib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]
2023-09-23 Replaced the switch footprint
    [ThumbsUp.kicad_pcb, ThumbsUp.sch]
2023-09-26 Retraced the lower board
    [ThumbsUp.kicad_pcb]
2023-10-01 Redefined the layout, checked in before splitting the layers.
    [ThumbsUp.kicad_pcb]
2023-10-01 Split the PCBs
    [ThumbsUp.kicad_pcb]
2023-10-01 Started tracing the secoh
    [ThumbsUp.kicad_pcb]
2023-10-02 Fixed and moved the cross board connectors.
    [ThumbsUp.kicad_pcb]
2023-10-02 Wired Level 2.
    [ThumbsUp.kicad_pcb, ThumbsUp.sch]
2023-10-03 Wired all levels
    [ThumbsUp.kicad_pcb]
2023-10-05 Added silkscreens, minor corrections before Gerbers generation.
2023-10-05 Generated Gerbers, POS and BOM files.
    [BOM ThumbsUp.csv, ThumbsUp BOM.csv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]
2023-10-24 Corrected switch footprint for Gateron sockets
    [ThumbsUp-B_Cu.gbr, ThumbsUp-B_Mask.gbr, ThumbsUp-B_Paste.gbr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]
2023-11-05 Adjusted some tracks around moved holes. Removed switch boundary from the top silkscreen.
2025-02-27 ThumbsUp v8: Updated description.
    [BOM ThumbsUp.csv, ThumbsUp BOM.csv, ThumbsUp-B_Mask.dxf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]
